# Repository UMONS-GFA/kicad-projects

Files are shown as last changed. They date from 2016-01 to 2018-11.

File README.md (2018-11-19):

# kicad-projects (NOT USED ANYMORE !)

## Configuring libraries in a project

Open your .sch file -> Preferences -> Component libraries  

Add component library files and choose your .lib files from the project_libs directory.  

## Configuring footprints in a project

* In project window, click new directory, rename it project_libs
* Add .lib files in this folder
* create project\_footprint.pretty sub-directory in project_libs
* Add kicad_mods in this sub-directory

Now in footprint editor, preferences -> footprint libraries manager-> project specific libraries click on on "Append Library"  

Example:  

Nickname: project  
Library path: ${KPRJMOD}/project\_libs/project\_footprints.pretty

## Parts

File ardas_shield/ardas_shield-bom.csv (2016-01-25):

Reference | Value | Footprint | Datasheet | Order_Code | MFN | MFP | Pitch_Spacing | Contact_Termination_Type | Gender | Case_Style
IC1 | DS1307 | Ardas_shield:SOIC-8-N | https://github.com/UMONS-GFA/kicad-gfa.pretty/blob/master/datasheets/46359.pdf | 9725253 | MAXIM INTEGRATED PRODUCTS | DS1307ZN+
X1 | CRYSTAL | Ardas_shield:XTAL_ABRACON_ABS07 | https://github.com/UMONS-GFA/kicad-gfa.pretty/blob/master/datasheets/1883680.pdf | 2467865 | ABRACON | ABS07-32.768KHZ-1-T
U3 | SN74LV8154 | Ardas_shield:TSSOP-20_4.4x6.5mm_Pitch0.65mm | https://github.com/UMONS-GFA/kicad-gfa.pretty/blob/master/datasheets/1996491.pdf | 1741273 | TEXAS INSTRUMENTS | SN74LV8154PW
U2 | 74HC165 | Ardas_shield:SOIC-16_3.9x9.9mm_Pitch1.27mm | https://github.com/UMONS-GFA/kicad-gfa.pretty/blob/master/datasheets/1831348.pdf | 9591192 | TEXAS INSTRUMENTS | SN74HC165D
U6 | SN74LV8154 | Ardas_shield:TSSOP-20_4.4x6.5mm_Pitch0.65mm | https://github.com/UMONS-GFA/kicad-gfa.pretty/blob/master/datasheets/1996491.pdf | 1741273 | TEXAS INSTRUMENTS | SN74LV8154PW
U4 | 74HC165 | Ardas_shield:SOIC-16_3.9x9.9mm_Pitch1.27mm | https://github.com/UMONS-GFA/kicad-gfa.pretty/blob/master/datasheets/1831348.pdf | 9591192 | TEXAS INSTRUMENTS | SN74HC165D
P1 | CONN_10 | Ardas_shield:Pin_Header_Straight_1x10 |  | 1278412 | FCI | 69190-410HLF | 2.54mm | Through Hole
P3 | CONN_8 | Ardas_shield:Pin_Header_Straight_1x08 |  | 1924194 | FCI | 68000-208HLF | 2.54mm | Through Hole
P5 | CONN_6 | Ardas_shield:Pin_Header_Straight_1x06 |  | 2132359 | MOLEX | 22-28-4064 | 2.54mm | Through Hole
P2 | CONN_8 | Ardas_shield:Pin_Header_Straight_1x08
P10 | CONN_01X03 | Ardas_shield:Pin_Header_Angled_1x03
P9 | CONN_01X03 | Ardas_shield:Pin_Header_Angled_1x03
P8 | CONN_01X03 | Ardas_shield:Pin_Header_Angled_1x03
P7 | CONN_01X03 | Ardas_shield:Pin_Header_Angled_1x03
P6 | TTL_COMM | Ardas_shield:Pin_Header_Angled_1x03 |  | 1593427 | MULTICOMP | MC34747 | 2.54mm | Through Hole | Header
U7 | 74LVC1G125 | Ardas_shield:SC-70-5
U8 | 74LVC1G125 | Ardas_shield:SC-70-5
U9 | 74LVC1G125 | Ardas_shield:SC-70-5
U5 | LD1117S33TR | Ardas_shield:SOT-223 | https://github.com/UMONS-GFA/kicad-gfa.pretty/blob/master/datasheets/1776449.pdf | 1202826 | STMICROELECTRONICS | LD1117S33TR
C1 | 47uF | Ardas_shield:C_0805
C2 | 47uF | Ardas_shield:C_0805
P4 | CONN_ICSP | Ardas_shield:Socket_Strip_Straight_2x03 |  | 1266033 | TE CONNECTIVITY / AMP | 5-534206-3 | 2.54mm | Through Hole | Receptacle
R1 | 10k | Ardas_shield:R_0805
RP1 | R_4x4.7k | kicad-gfa local:R_Array_Convex_4x0603
RP4 | R_4x10k | kicad-gfa local:R_Array_Convex_4x0603 | https://github.com/UMONS-GFA/kicad-gfa.pretty/blob/master/datasheets/1730408.pdf
RP3 | R_4x10k | kicad-gfa local:R_Array_Convex_4x0603 | https://github.com/UMONS-GFA/kicad-gfa.pretty/blob/master/datasheets/1730408.pdf
BT1 | Battery | Ardas_shield:BATTERY_KEYSTONE_12mm | https://github.com/UMONS-GFA/kicad-gfa.pretty/blob/master/datasheets/1696457.pdf | 1650692 | KEYSTONE | 3000
U1 | 74HC595 | Ardas_shield:SOIC-16_7.5x10.3mm_Pitch1.27mm | https://github.com/UMONS-GFA/kicad-gfa.pretty/blob/master/datasheets/1970412.pdf | 1595418 | TEXAS INSTRUMENTS | SN74HC595DW
D1 | LED_RABG | Ardas_shield:led-P-LCC-4-3
RP2 | R_4x10k | kicad-gfa local:R_Array_Convex_4x0603
RP5 | R_4x10k | kicad-gfa local:R_Array_Convex_4x0603 | https://github.com/UMONS-GFA/kicad-gfa.pretty/blob/master/datasheets/1730408.pdf
CON1 | SD_Card | Ardas_shield:microsd_socket | https://github.com/UMONS-GFA/kicad-gfa.pretty/blob/master/datasheets/1717993.pdf | 2334075 | MOLEX | 503182-1853
R2 | 150 | Ardas_shield:R_0805 |  | 9233903RL | YAGEO (PHYCOMP) | RC0805JR-07150RL |  |  |  | 0805 [2012 Metric]
R3 | 100 | Ardas_shield:R_0805 |  | 9233881 | YAGEO (PHYCOMP) | RC0805JR-07100RL |  |  |  | 0805 [2012 Metric]
R4 | 100 | Ardas_shield:R_0805 |  | 9233881 | YAGEO (PHYCOMP) | RC0805JR-07100RL |  |  |  | 805 [2012 Metric]
JP1 | Jumper_NO_Small | RTC_Ardas_test:small_no_jumper
JP2 | Jumper_NO_Small | RTC_Ardas_test:small_no_jumper

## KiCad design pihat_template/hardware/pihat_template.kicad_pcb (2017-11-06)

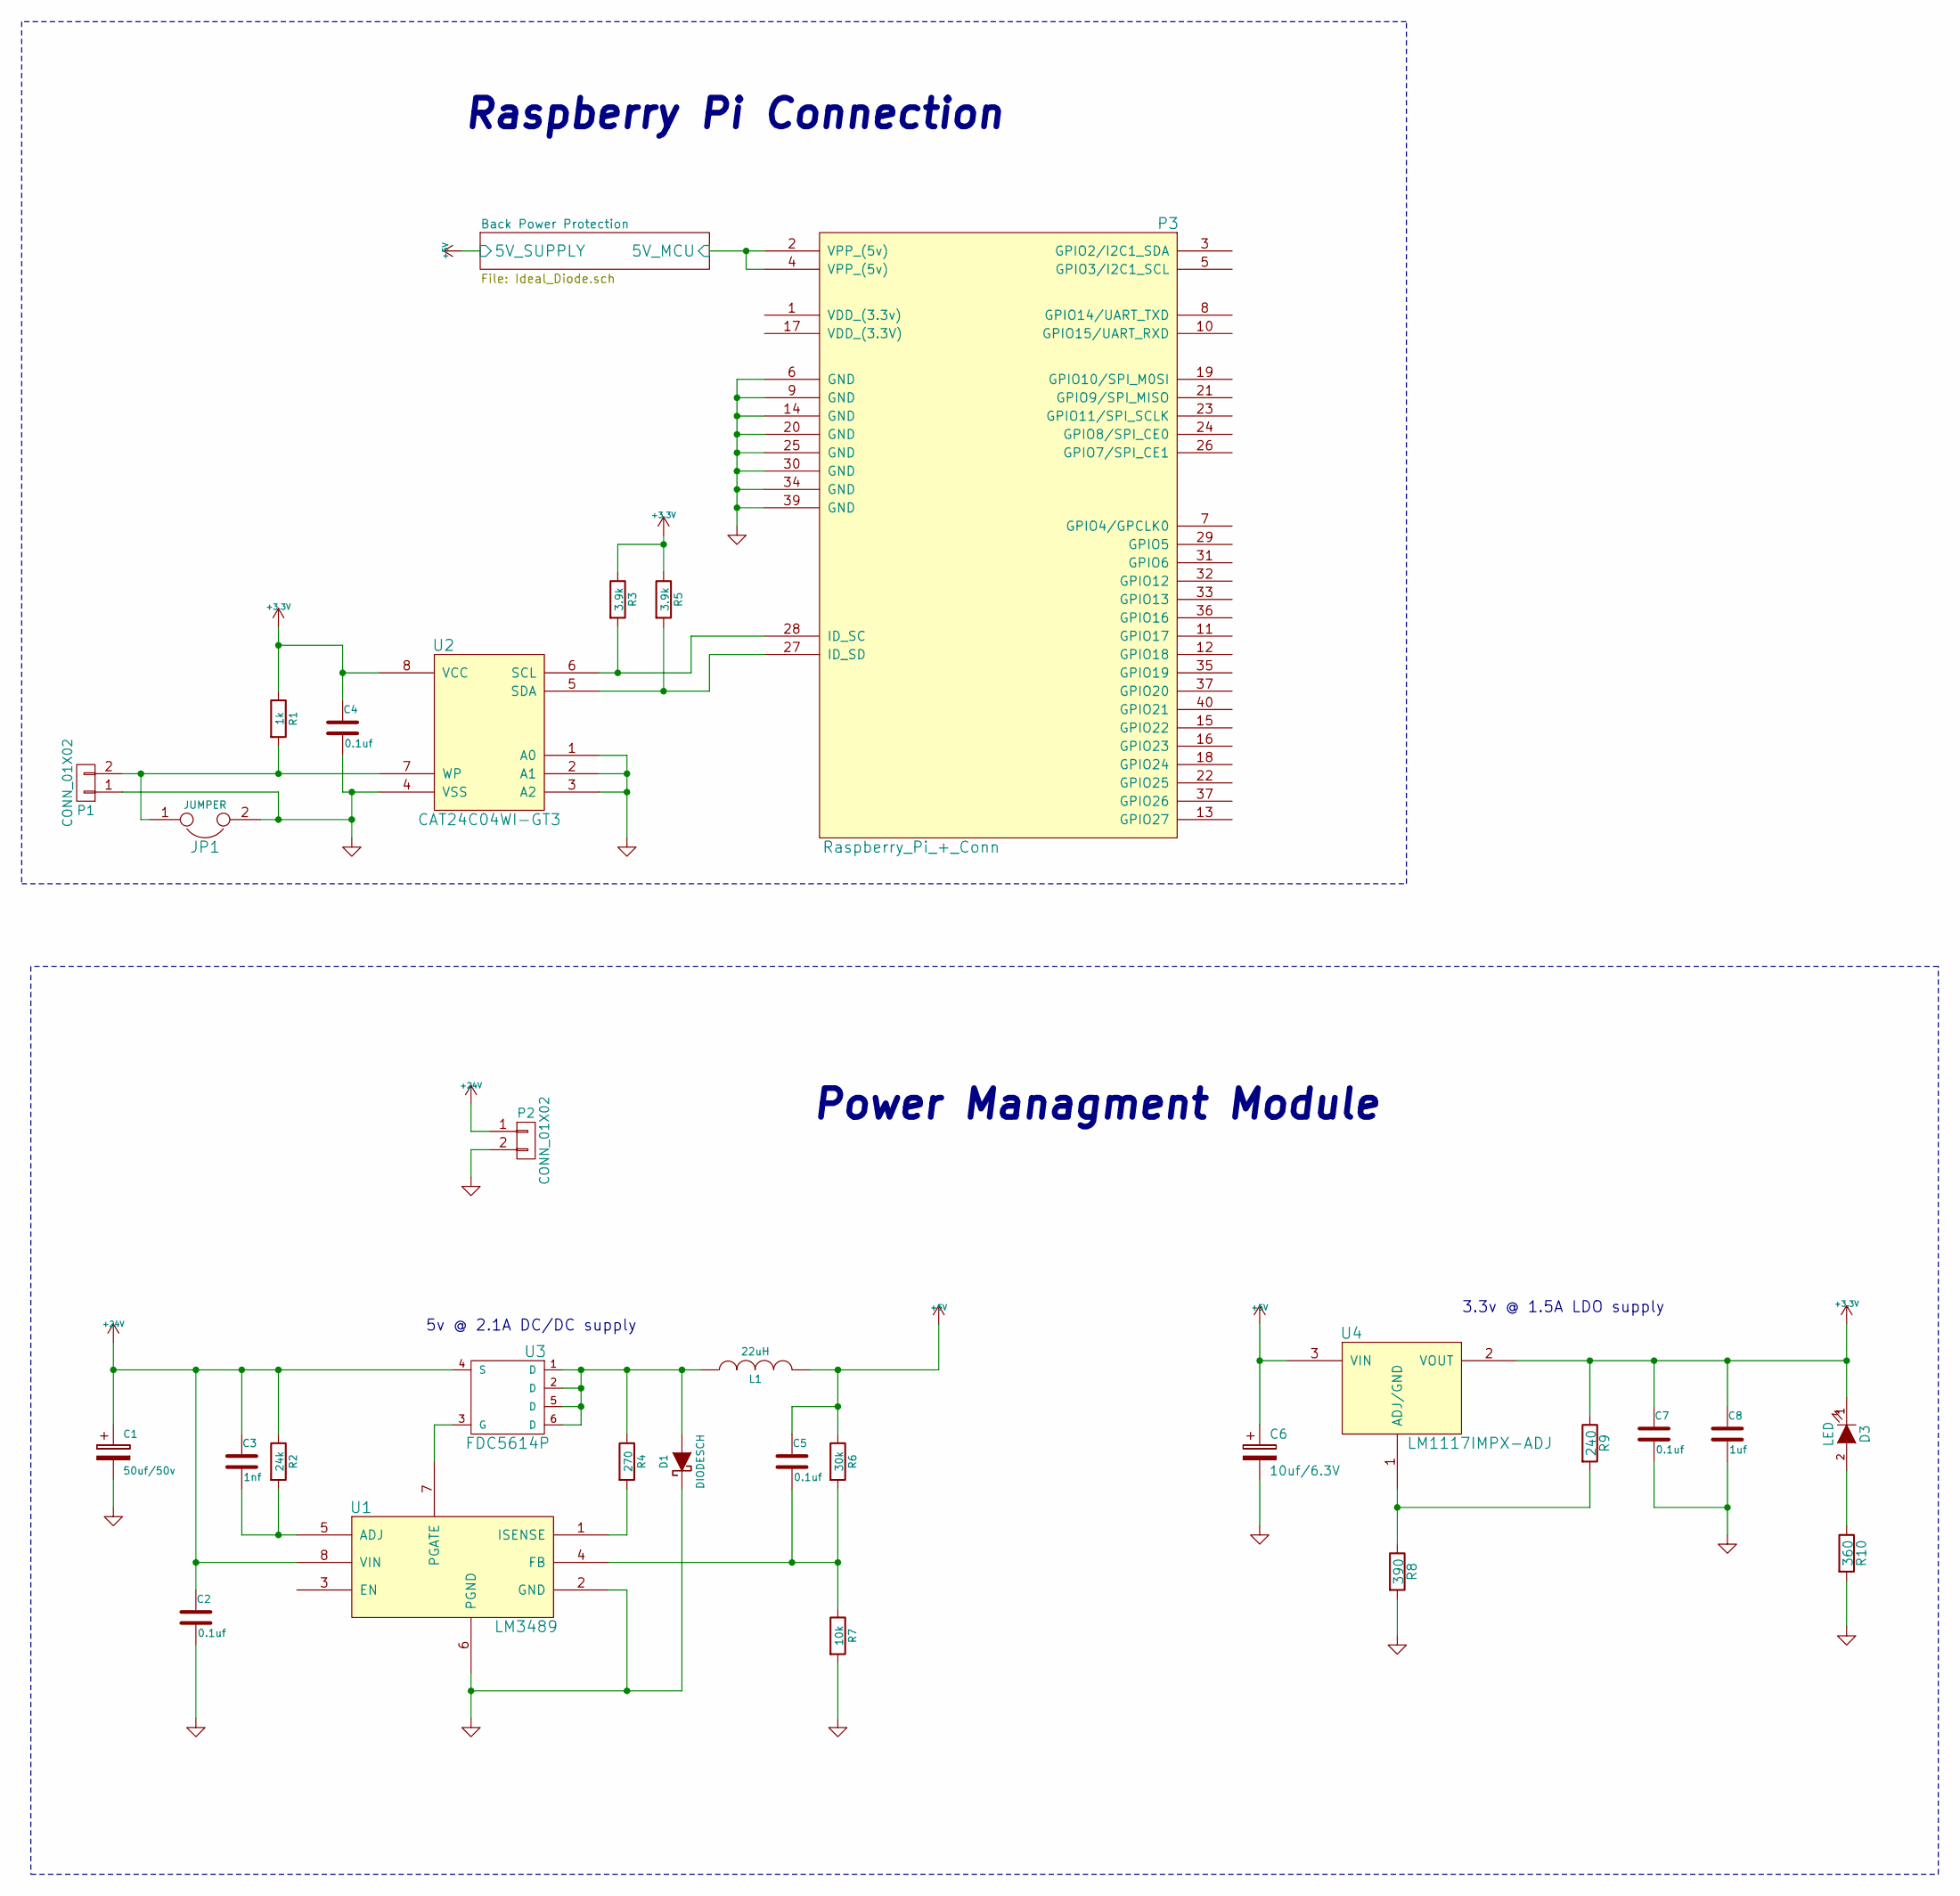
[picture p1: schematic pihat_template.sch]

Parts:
C1: 50uf/50v; c_elec_6.3x7.7; Mouser Part No. 647-UUR1H470MCL6GS
C2, C4, C5, C7: 0.1uf; c_0805; Mouser Part No. 810-C1005X5R1H104K
C3: 1nf; c_0805; Mouser Part No. 810-C1005C0G2A102J5C
C6: 10uf/6.3V; c_elec_4x5.3; Mouser Part No. 5985-AVS16V100-F
C8: 1uf; c_0805; Mouser Part No. 810-C1005X5R1H104K
D1: DIODESCH; do214aa; Farnell Part No. 2628293
D3: LED; Led_0603; Mouser Part No. 743-HT-191USD
JP1: JUMPER; r_0603; Farnell Part No. ?
L1: 22uH; inductor_smd_8x5mm; Mouser Part No. 652-SRN8040-220M
P1: CONN_01X02; pin_strip_2; Farnell Part No. ?
P2: CONN_01X02; mkds_1,5-2; Mouser Part No. 651-1904383
P3: Raspberry_Pi_+_Conn; pin_socket_20x2_mirrored; Mouser Part No. 517-30340-6002
R1: 1k; r_0805; Mouser Part No. 754-RR0510P-102D
R2: 24k; r_0805; Mouser Part No. 71-CRCW0402-24K-E3
R3, R5: 3.9k; r_0805; Mouser Part No. 71-CRCW04023K90FKED
R4: 270; r_0805; Mouser Part No. 667-ERJ-P6WJ271V
R6: 30k; r_0805; Mouser Part No. 594-MCT06030C3002FP5
R7: 10k; r_0805; Mouser Part No. 71-CRCW0603-10K-E3
R8: 390; r_0805; Mouser Part No. 594-MCT06030C3900FP5
R9: 240; r_0805; Mouser Part No. 754-RR0816P-241D
R10: 360; r_0805; Mouser Part No. 71-CRCW0603316RFKEB
U1: LM3489; VSSOP-8_3.0x3.0mm_Pitch0.65mm; Farnell Part No. 1312570
U2: CAT24C04WI-GT3; Farnell Part No. 2463704
U3: FDC5614P; Mouser Part No. 512-FDC5614P
U4: LM1117IMPX-ADJ; sot223; Mouser Part No. 926-M1117IMPXADJNOPB

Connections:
+3V3: C4.1, C7.1, C8.1, D3.1 (K), R1.1, R3.1, R5.1, R9.1, U2.8 (VCC), U4.2 (VOUT)
+5V: C5.1, C6.1, L1.2, R6.1, U4.3 (VIN); also elsewhere on the board
+24V: C1.1, C2.1, C3.1, P2.1, R2.1, U1.8 (VIN), U3.4 (S)
/Back Power Protection/5V_MCU: P3.2 (VPP_(5v)), P3.4 (VPP_(5v)); also elsewhere on the board
GND: C1.2, C2.2, C4.2, C6.2, C7.2, C8.2, D1.1 (K), JP1.2, P1.1, P2.2, P3.6 (GND), P3.9 (GND), P3.14 (GND), P3.20 (GND), P3.25 (GND), P3.30 (GND), P3.34 (GND), P3.39 (GND), R7.2, R8.2, R10.2, U1.2 (GND), U1.6 (PGND), U2.1 (A0), U2.2 (A1), U2.3 (A2), U2.4 (VSS); also elsewhere on the board
unnamed: C3.2, R2.2, U1.5 (ADJ)
unnamed: C5.2, R6.2, R7.1, U1.4 (FB)
unnamed: D1.2 (A), L1.1, R4.1, U3.1 (D), U3.2 (D), U3.5 (D), U3.6 (D)
unnamed: D3.2 (A), R10.1
unnamed: JP1.1, P1.2, R1.2, U2.7 (WP)
unnamed: P3.27 (ID_SD), R5.2, U2.5 (SDA)
unnamed: P3.28 (ID_SC), R3.2, U2.6 (SCL)
unnamed: R4.2, U1.1 (ISENSE)
unnamed: R8.1, R9.2, U4.1 (ADJ/GND)
unnamed: U1.7 (PGATE), U3.3 (G)

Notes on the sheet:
Raspberry Pi Connection
Power Managment Module
5v @ 2.1A DC/DC supply
3.3v @ 1.5A LDO supply

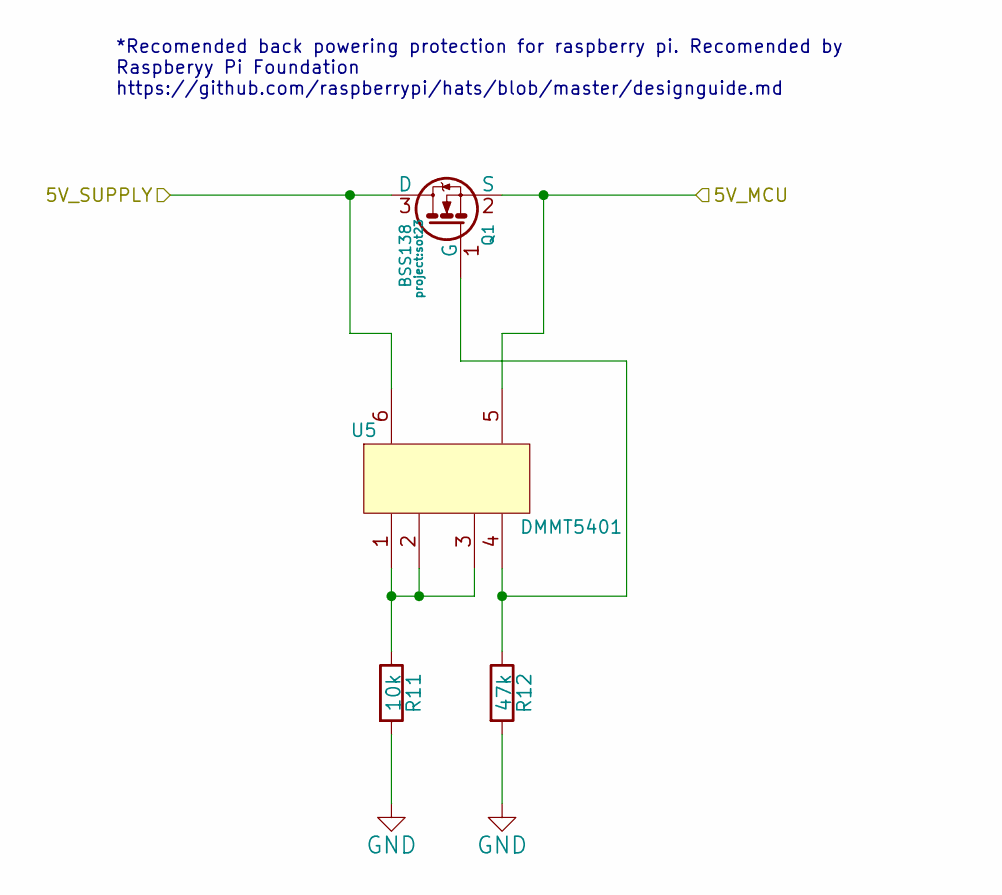
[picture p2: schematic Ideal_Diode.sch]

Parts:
Q1: BSS138; sot23; Mouser Part No. 621-DMG2305UX-13
R11: 10k; r_0805; Mouser Part No. 71-CRCW0402-10K-E3
R12: 47k; r_0805; Mouser Part No. 667-ERJ-2RKF4702X
U5: DMMT5401; sot23-6; Mouser Part No. 621-DMMT5401-7-F

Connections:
+5V: Q1.3 (D), U5.6; also elsewhere on the board
/Back Power Protection/5V_MCU: Q1.2 (S), U5.5; also elsewhere on the board
GND: R11.2, R12.2; also elsewhere on the board
unnamed: Q1.1 (G), R12.1, U5.4
unnamed: R11.1, U5.1, U5.2, U5.3

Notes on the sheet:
*Recomended back powering protection for raspberry pi. Recomended by Raspberyy Pi Foundation https://github.com/raspberrypi/hats/blob/master/designguide.md

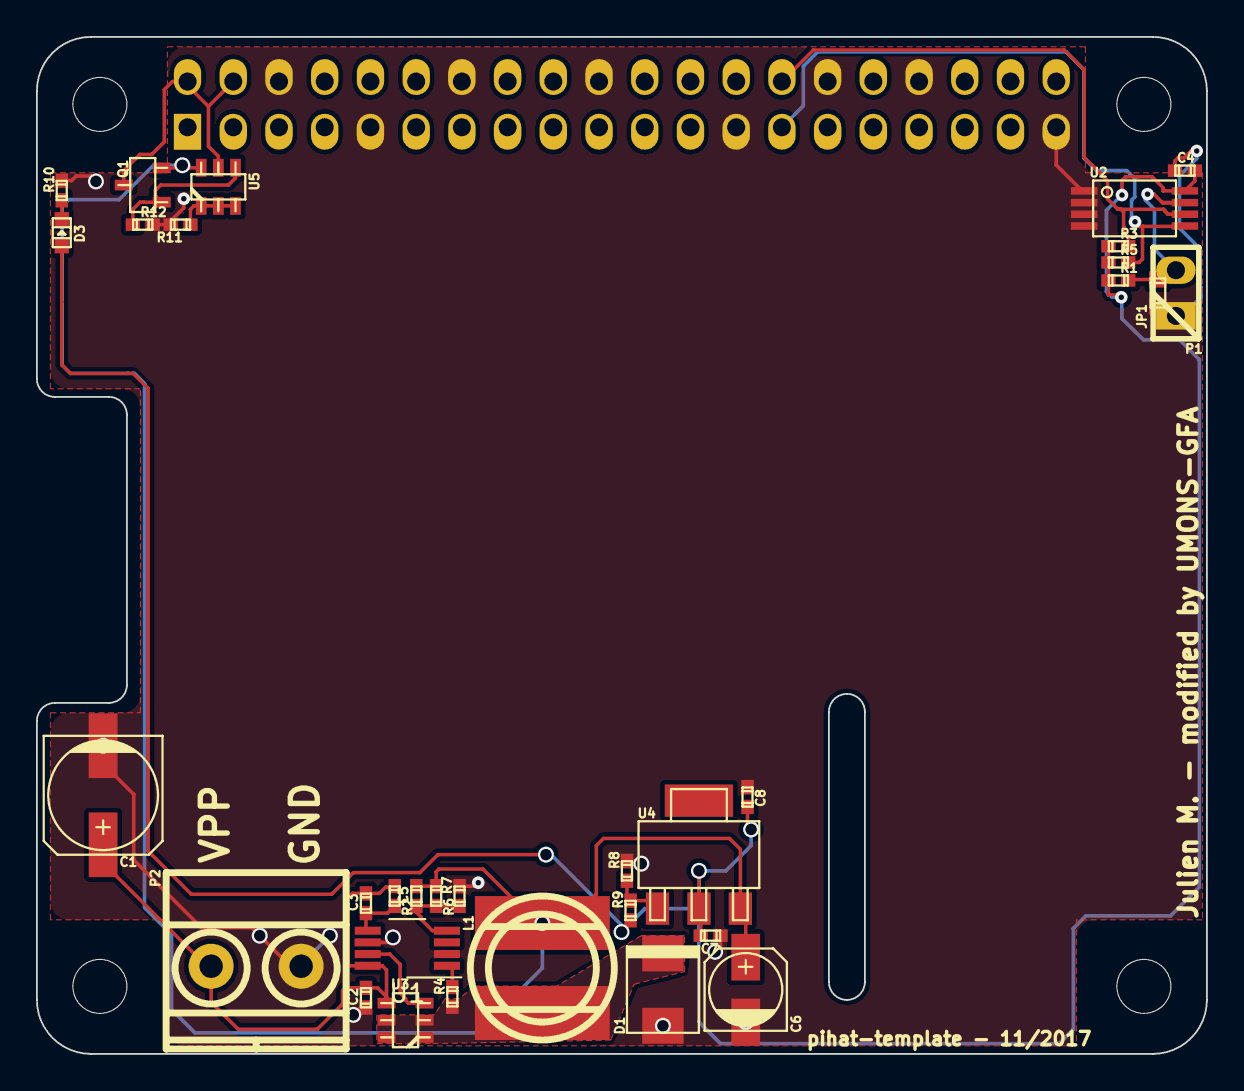
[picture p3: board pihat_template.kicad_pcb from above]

Board: 2 copper layers, 65.0 x 56.5 mm, 33 parts (1 on the bottom side), 17 nets.

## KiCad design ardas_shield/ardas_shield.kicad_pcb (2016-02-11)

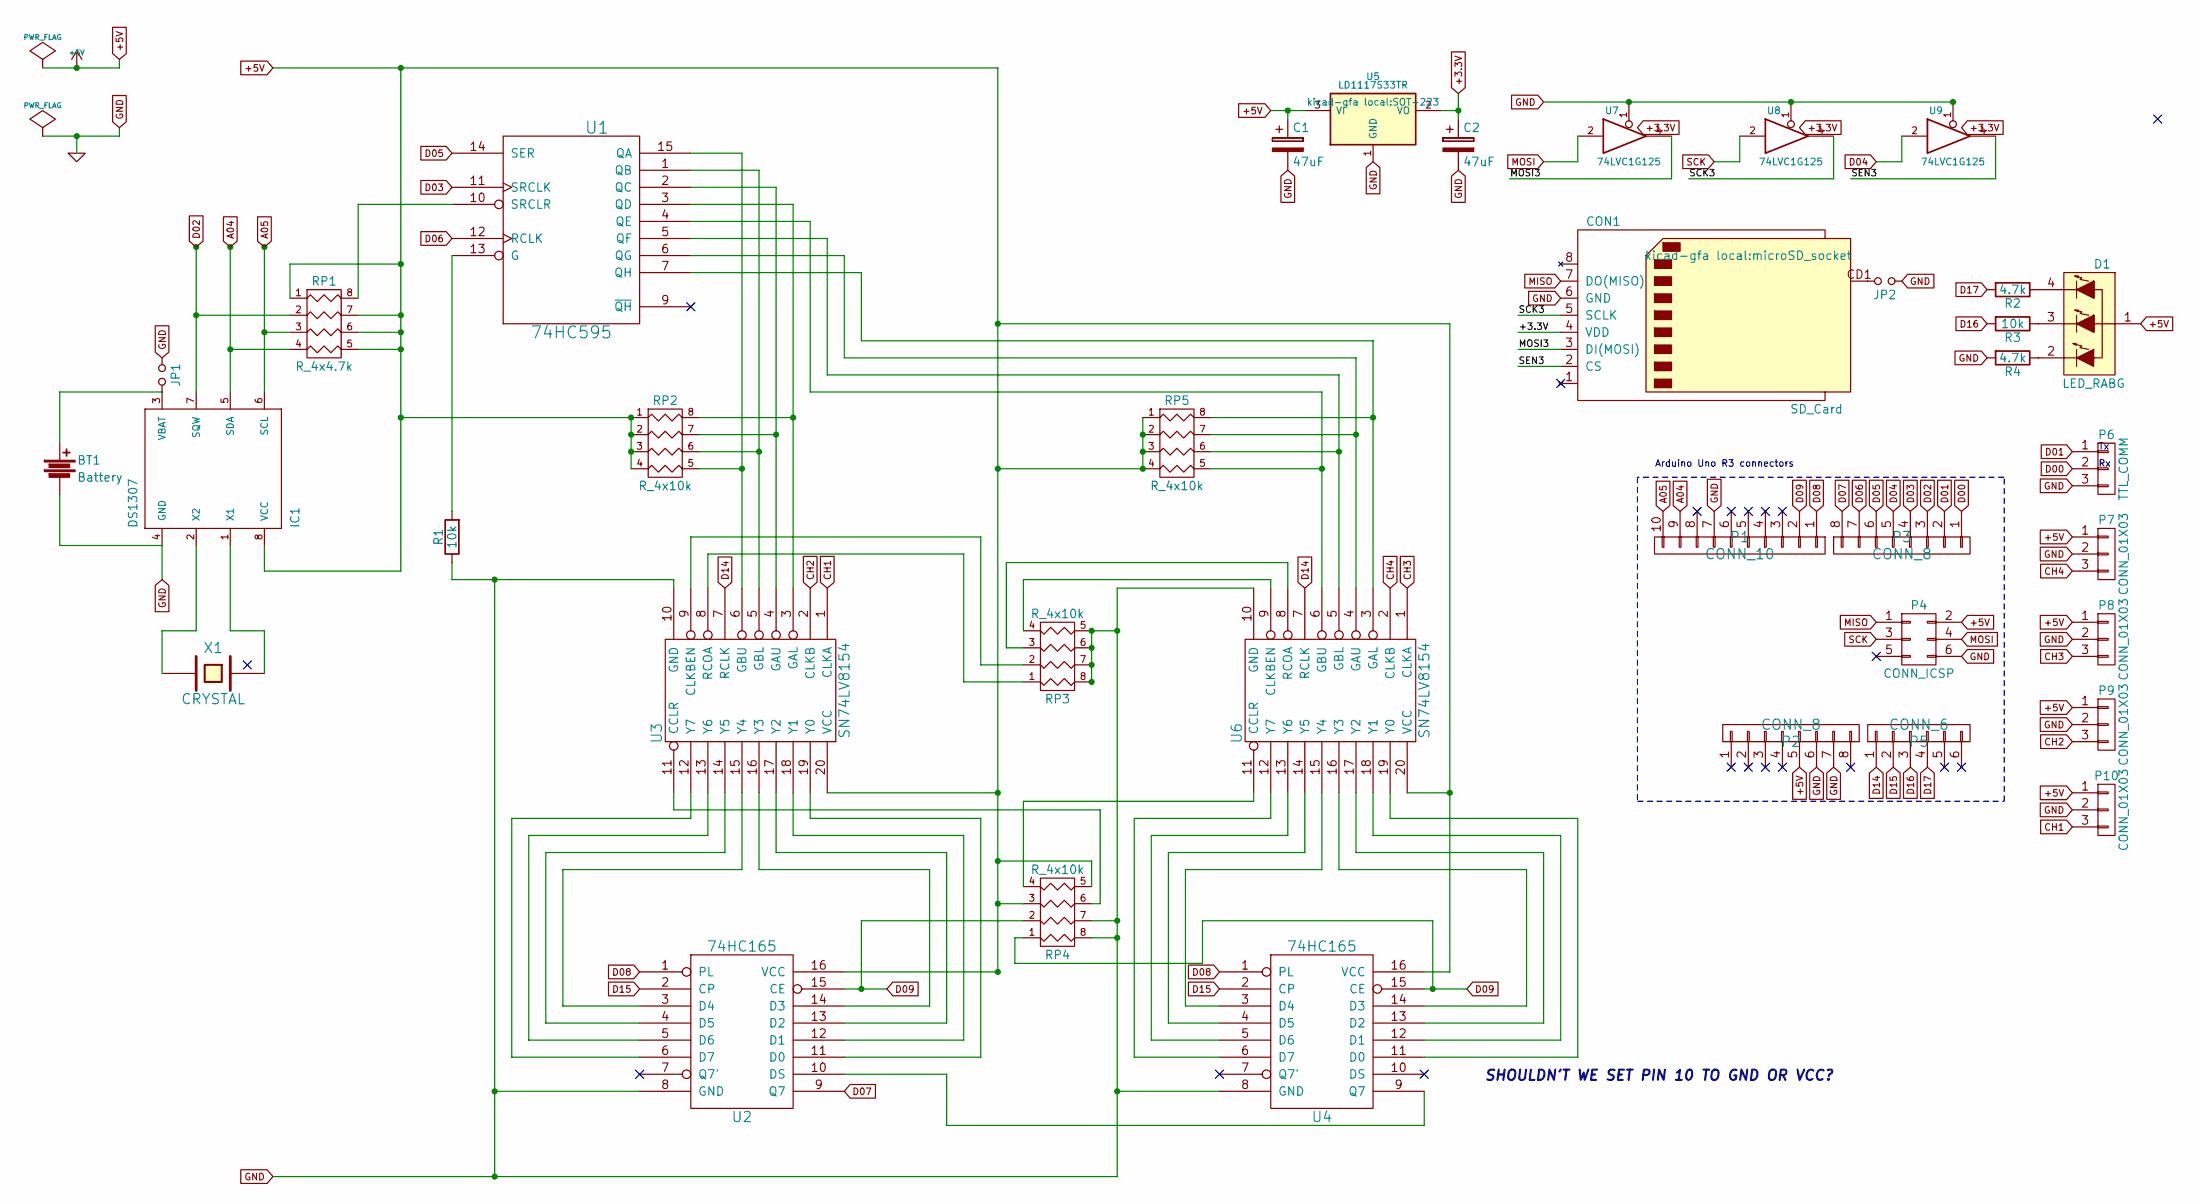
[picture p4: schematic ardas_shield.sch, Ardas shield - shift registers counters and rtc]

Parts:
BT1: Battery; BATTERY_KEYSTONE_12mm
C1, C2: 47uF; C_0805
CON1: SD_Card; microSD_socket
D1: LED_RABG; led-P-LCC-4-3
IC1: DS1307; SOIC-8-N
JP1, JP2: Jumper_NO_Small; small_no_jumper
P1: CONN_10; Pin_Header_Straight_1x10
P2, P3: CONN_8; Pin_Header_Straight_1x08
P4: CONN_ICSP; Socket_Strip_Straight_2x03
P5: CONN_6; Pin_Header_Straight_1x06
P6: TTL_COMM; Pin_Header_Angled_1x03
P7, P8, P9, P10: CONN_01X03; Pin_Header_Angled_1x03
R1, R3: 10k; R_0805
R2, R4: 4.7k; R_0805
RP1: R_4x4.7k; R_Array_Convex_4x0603
RP2, RP3, RP4, RP5: R_4x10k; R_Array_Convex_4x0603
U1: 74HC595; SOIC-16_7.5x10.3mm_Pitch1.27mm
U2, U4: 74HC165; SOIC-16_3.9x9.9mm_Pitch1.27mm
U3, U6: SN74LV8154; TSSOP-20_4.4x6.5mm_Pitch0.65mm
U5: LD1117S33TR; SOT-223
U7, U8, U9: 74LVC1G125; SC-70-5
X1: CRYSTAL; XTAL_ABRACON_ABS07

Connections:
+3.3V: C2.1, CON1.4 (VDD), U1.16 (VCC), U5.2 (VO), U7.5 (VCC), U8.5 (VCC), U9.5 (VCC)
+5V: C1.1, D1.1 (COMMON_ANODE), IC1.8 (VCC), P2.5, P4.2, P7.1, P8.1, P9.1, P10.1, RP1.1, RP1.5 (R4), RP1.6 (R3), RP1.7 (R2), RP2.1, RP2.2, RP2.3, RP2.4, RP4.3, RP4.5 (R4), RP5.1, RP5.2, RP5.3, RP5.4, U2.16 (VCC), U3.20 (VCC), U4.16 (VCC), U5.3 (VI), U6.20 (VCC)
/MOSI3: CON1.3 (DI(MOSI)), U7.4
/SCK3: CON1.5 (SCLK), U8.4
/SEN3: CON1.2 (CS), U9.4
A04: IC1.5 (SDA), P1.9, RP1.4
A05: IC1.6 (SCL), P1.10, RP1.3
CH1: P10.3, U3.1 (CLKA)
CH2: P9.3, U3.2 (CLKB)
CH3: P8.3, U6.1 (CLKA)
CH4: P7.3, U6.2 (CLKB)
D00: P3.1, P6.2
D01: P3.2, P6.1
D02: IC1.7 (SQW), P3.3, RP1.2
D03: P3.4, U1.11 (SRCLK)
D04: P3.5, U9.2
D05: P3.6, U1.14 (SER)
D06: P3.7, U1.12 (RCLK)
D07: P3.8, U2.9 (Q7)
D08: P1.1, U2.1 (PL), U4.1 (PL)
D09: P1.2, RP4.1, RP4.2, U2.15 (CE), U4.15 (CE)
D14: P5.1, U3.7 (RCLK), U6.7 (RCLK)
D15: P5.2, U2.2 (CP), U4.2 (CP)
D16: P5.3, R3.2
D17: P5.4, R2.2
GND: BT1.2, C1.2, C2.2, CON1.6 (GND), IC1.4 (GND), JP1.1, JP2.1, P1.7, P2.6, P2.7, P4.6, P6.3, P7.2, P8.2, P9.2, P10.2, R1.1, R4.2, RP3.5 (R4), RP3.6 (R3), RP3.7 (R2), RP3.8 (R1), RP4.7 (R2), RP4.8 (R1), U1.8 (GND), U2.8 (GND), U3.10 (GND), U4.8 (GND), U5.1 (GND), U6.10 (GND), U7.1, U7.3 (GND), U8.1, U8.3 (GND), U9.1, U9.3 (GND)
MISO: CON1.7 (DO(MISO)), P4.1
MOSI: P4.4, U7.2
unnamed: BT1.1, IC1.3 (VBAT), JP1.2
unnamed: CON1.CD1, JP2.2
unnamed: D1.2 (BLUE_CATHODE), R4.1
unnamed: D1.3 (GREEN_CATHODE), R3.1
unnamed: D1.4 (RED_CATHODE), R2.1
unnamed: IC1.1 (X1), X1.1
unnamed: IC1.2 (X2), X1.2
unnamed: R1.2, U1.13 (G)
unnamed: RP1.8 (R1), U1.10 (SRCLR)
unnamed: RP2.5 (R4), U1.15 (QA), U3.6 (GBU)
unnamed: RP2.6 (R3), U1.1 (QB), U3.5 (GBL)
unnamed: RP2.7 (R2), U1.2 (QC), U3.4 (GAU)
unnamed: RP2.8 (R1), U1.3 (QD), U3.3 (GAL)
unnamed: RP3.1, U3.8 (RCOA)
unnamed: RP3.2, U3.9 (CLKBEN)
unnamed: RP3.3, U6.8 (RCOA)
unnamed: RP3.4, U6.9 (CLKBEN)
unnamed: RP4.4, U6.11 (CCLR)
unnamed: RP4.6 (R3), U3.11 (CCLR)
unnamed: RP5.5 (R4), U1.4 (QE), U6.6 (GBU)
unnamed: RP5.6 (R3), U1.5 (QF), U6.5 (GBL)
unnamed: RP5.7 (R2), U1.6 (QG), U6.4 (GAU)
unnamed: RP5.8 (R1), U1.7 (QH), U6.3 (GAL)
unnamed: U2.3 (D4), U3.15 (Y4)
unnamed: U2.4 (D5), U3.14 (Y5)
unnamed: U2.5 (D6), U3.13 (Y6)
unnamed: U2.6 (D7), U3.12 (Y7)
unnamed: U2.10 (DS), U4.9 (Q7)
unnamed: U2.11 (D0), U3.19 (Y0)
unnamed: U2.12 (D1), U3.18 (Y1)
unnamed: U2.13 (D2), U3.17 (Y2)
unnamed: U2.14 (D3), U3.16 (Y3)
unnamed: U4.3 (D4), U6.15 (Y4)
unnamed: U4.4 (D5), U6.14 (Y5)
unnamed: U4.5 (D6), U6.13 (Y6)
unnamed: U4.6 (D7), U6.12 (Y7)
unnamed: U4.11 (D0), U6.19 (Y0)
unnamed: U4.12 (D1), U6.18 (Y1)
unnamed: U4.13 (D2), U6.17 (Y2)
unnamed: U4.14 (D3), U6.16 (Y3)
SCK: P4.3, U8.2

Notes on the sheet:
Arduino Uno R3 connectors
SHOULDN'T WE SET PIN 10 TO GND OR VCC?

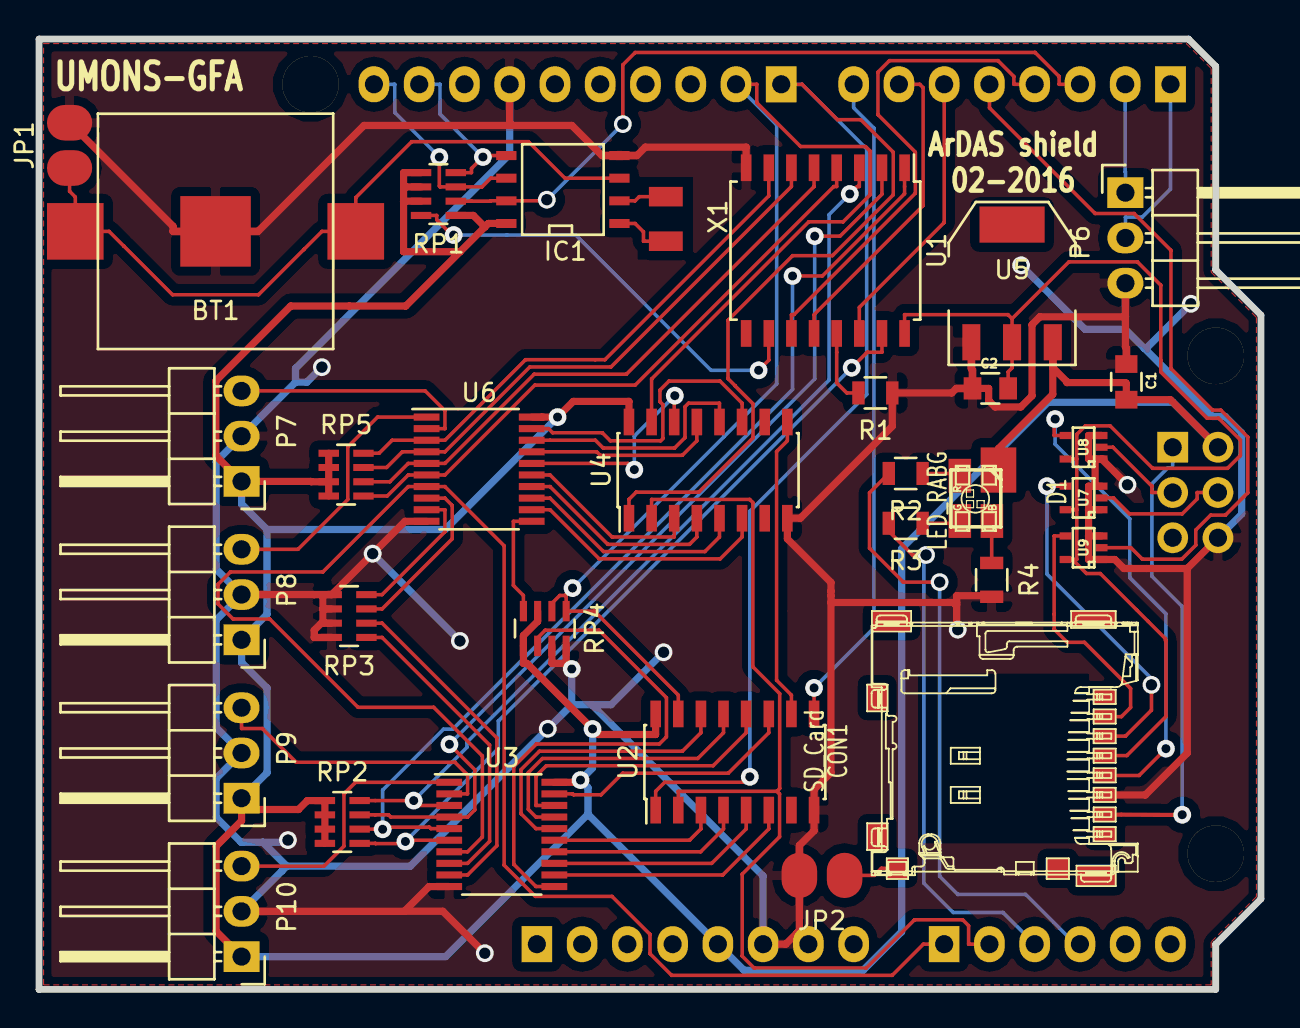
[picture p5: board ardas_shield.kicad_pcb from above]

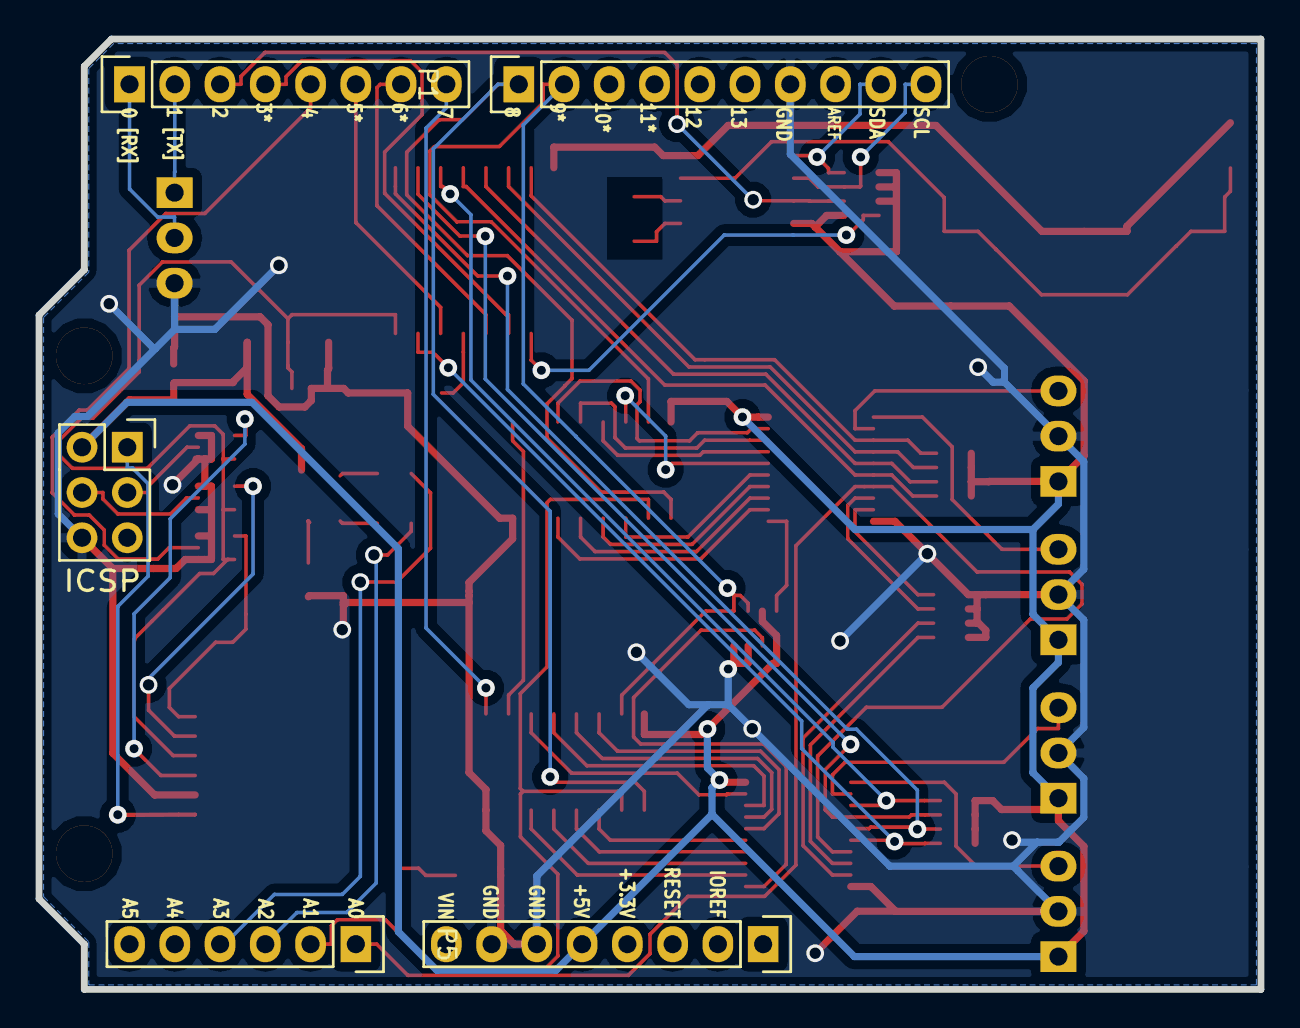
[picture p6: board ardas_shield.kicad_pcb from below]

Board: 2 copper layers, 68.6 x 53.3 mm, 40 parts (5 on the bottom side), 69 nets.

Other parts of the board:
V4, V5, V6: MountingHole_125mil

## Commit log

2016-01-13 add initial files for ArDAS shield
    [ardas_shield.dsn, ardas_shield.kicad_pcb, ardas_shield.sch]
2016-01-13 add more components
    [ardas_shield.sch]
2016-01-13 rename Ardas
    [ardas_shield.dsn, ardas_shield.kicad_pcb, ardas_shield.sch]
2016-01-13 Updated ardas_shield geometry and microSD. Rerouted shield
    [ardas_shield.dsn, ardas_shield.kicad_pcb]
2016-01-15 updated to v0.49
    [ardas_shield.kicad_pcb, ardas_shield.sch]
2016-01-15 add datasheet links
    [ardas_shield.sch]
2016-01-19 changed resitances arrays footprints
    [ardas_shield.dsn, ardas_shield.kicad_pcb, ardas_shield.sch]
2016-01-21 upgraded Ardas shield + RTC_tester
    [RTC_tester.dsn, RTC_tester.kicad_pcb, ardas_shield+RTC_tester.kicad_pcb]
2016-01-25 add details for BOM
    [ardas_shield.sch]
2016-01-25 add BOM
    [ardas_shield-bom.csv]
2016-02-08 updated ardas_shield+RTC_tester.kicad_pcb
    [ardas_shield+RTC_tester.kicad_pcb]
2016-02-08 ardas shield
    [ardas_shield+RTC_tester.kicad_pcb]
2016-02-11 modified RGB LED and SD-Card pinout and buffer VCC
    [ardas_shield.sch]
2016-02-11 updated SD card and RGB-LED
    [RTC_tester.dsn, RTC_tester.kicad_pcb, ardas_shield+RTC_tester.kicad_pcb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]
2017-09-29 added pihat_template
    [Ideal_Diode.sch, pihat_template.kicad_pcb, pihat_template.sch]
2017-10-31 changed LM3489 footprint
    [pihat_template.kicad_pcb]
2017-10-31 add VSSOP as a project footprint
    [pihat_template.kicad_pcb]
2017-10-31 update components
    [pihat_template.sch]
2017-10-31 added farnell part no.
    [Ideal_Diode.sch, pihat_template.sch]
2017-11-02 added silk UMONS-GFA + name
    [pihat_template.kicad_pcb]
2017-11-06 pihat 1-wire first commit
    [Ideal_Diode.sch, pihat_1wire.kicad_pcb, pihat_1wire.sch]
2017-11-06 updated vias for EuroCircuits standards
    [pihat_template.kicad_pcb]
2017-11-06 remove wrong release
    [Ideal_Diode.sch, pihat_1wire.kicad_pcb, pihat_1wire.sch]
2017-11-06 add gigalib libraries
    [7Segment_16Sep2013.kicad_pcb, BNC-Sockets_RevA.kicad_pcb, Buzzer_Beeper_RevA_25Oct2010.kicad_pcb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]
2017-11-06 added and links to 3D models for modules in project lib
    [Ideal_Diode.sch, pihat_template.kicad_pcb, pihat_template.sch]
2017-11-06 raspberry pi connector moved to back side of board
    [pihat_template.kicad_pcb]
2017-11-07 add missing component
    [pihat_template.kicad_pcb]
2017-11-16 refactor larger components
    [Ideal_Diode.sch, pihat_template.kicad_pcb, pihat_template.sch]
2017-11-16 refactor large components
    [Ideal_Diode.sch, pihat_template.kicad_pcb, pihat_template.sch]
2017-11-16 Refactored PCB with larger components
    [pihat_template.kicad_pcb]

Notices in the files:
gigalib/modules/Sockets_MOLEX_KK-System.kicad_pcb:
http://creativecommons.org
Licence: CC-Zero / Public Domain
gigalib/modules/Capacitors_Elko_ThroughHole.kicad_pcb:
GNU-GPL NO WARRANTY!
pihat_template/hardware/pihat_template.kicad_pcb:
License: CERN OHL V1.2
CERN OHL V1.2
